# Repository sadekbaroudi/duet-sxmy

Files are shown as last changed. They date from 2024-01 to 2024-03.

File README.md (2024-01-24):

# duet

## CAUTION

This is based on the work of zzeneg. The intent of this fork is to convert the duet into a standard x / min y spacing verison, to be used with [CMY keycaps](https://github.com/sadekbaroudi/fingerpunch/tree/master/keycaps/CMY)  

In addition to this, I have added strong pinky stagger.  

Please reach out in the [fingerpunch discord server](https://fingerpunch.xyz/discord) if you are interested in building this.  

Everything below is the original readme, and has not been updated to reflect the changes in this repository.

--------------------------------------------------------------------------------------------

Wireless unibody/unsplit portable keyboard.

(https://www.youtube.com/watch?v=R7SToNp1SO8)

## Features

- wireless (nice!nano MCU)
- unibody that can be disassembled into two parts for traveling
- 40 Choc V1 switches
- 1 rotary encoder and 1 five-way switch
- reversible PCB
- 3D printed case
- nice!view support

## Photos

https://github.com/zzeneg/duet/assets/910255/740595a8-76a9-42da-903d-3cff3896a925





[...more](./images)

## Firmware

[zmk-config](https://github.com/zzeneg/zmk-config/tree/duet) - my custom keymap, use it for testing only. Fork and create your own keymap instead.

## Instructions

[Build guide](./guide/readme.md)

All files are available in repo or [GitHub release](https://github.com/zzeneg/duet/releases/latest).

## Support

If you like my work and want to support my future designs, please consider [sponsorship](https://github.com/sponsors/zzeneg).

#### Sponsors



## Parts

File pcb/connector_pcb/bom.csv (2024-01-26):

Designator | Footprint | Quantity | Value | LCSC Part #
H1, H2 | Hole_M2-TH | 2 | MountingHole
VIK_K1 | Connector_VIK-magnetic-keyboard | 1 | Connector_VIK-keyboard
VIK_K2, VIK_K4 | Connector_FFC-12pin-1mm-vertical | 2 | Connector_VIK-keyboard

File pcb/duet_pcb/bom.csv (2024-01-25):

Designator | Footprint | Quantity | Value | LCSC Part #
D1, D10, D11, D12, D13, D14, D15, D16, D17, D18, D19, D2, D20, D3, D4, D5, D6, D7, D8, D9 | Diode_1N4148-SOD123-reversible-flip3d | 20 | D
H1, H2, H3, H4, H5, H6, H7, H8 | Hole_M2-TH | 8 | MountingHole
J1 | MCU_nice-nano | 1 | N!N
J2 | Connector_JST-1x02-2.00mm | 1 | Conn_01x02_Socket
J4 | Display_nice-view | 1 | Display_nice-view
J8, J9 | Connector_FFC-12pin-1mm-horizontal | 2 | Conn_01x12_Socket
S1 | Button_5way-SKRHABE010 | 1 | Button_5way-SKRHABE010
SW1, SW10, SW11, SW12, SW13, SW14, SW15, SW16, SW17, SW18, SW19, SW2, SW20, SW3, SW4, SW5, SW6, SW7, SW8, SW9 | Switch_ChocV1-hotswap-minY-reversible | 20 | Switch
SW21 | Button_SW_SPST_SKQG_WithoutStem | 1 | SW_Push
SW22 | Switch_SPDT-PCM12 | 1 | SW_SPDT
SW23 | RotaryEncoder_EC11 | 1 | RotaryEncoder_Switch

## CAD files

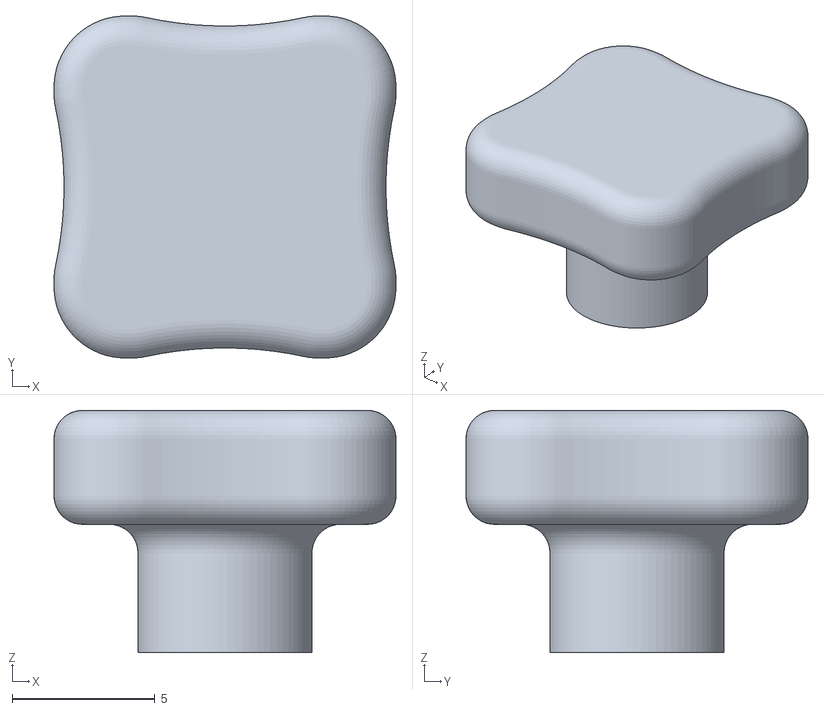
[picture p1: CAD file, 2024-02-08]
case/knob-5way-ergo-2.2.stl
12.0 x 12.0 x 8.50

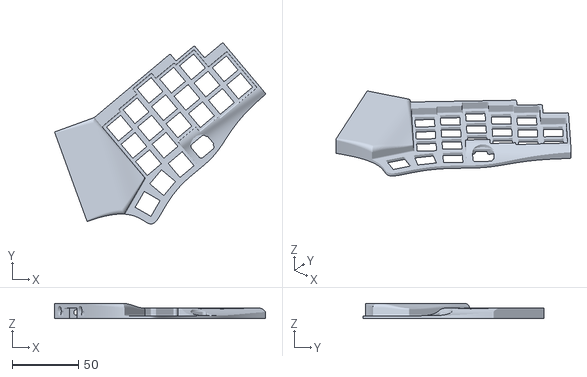
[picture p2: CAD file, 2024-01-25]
case/original/case_duet v39_top-right.stl
159.4 x 136.7 x 11.7

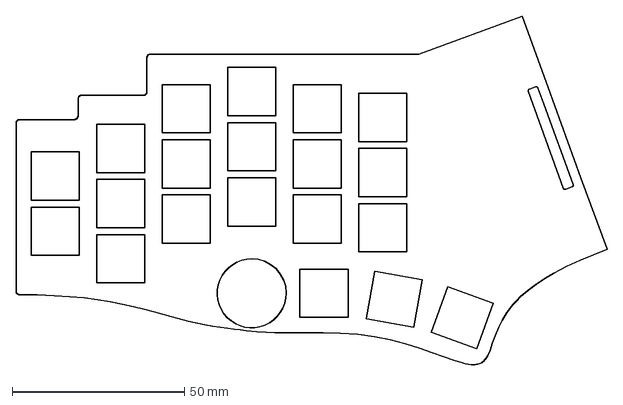
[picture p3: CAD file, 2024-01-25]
pcb/pcb-brd.dxf
171.5 x 101.1 mm

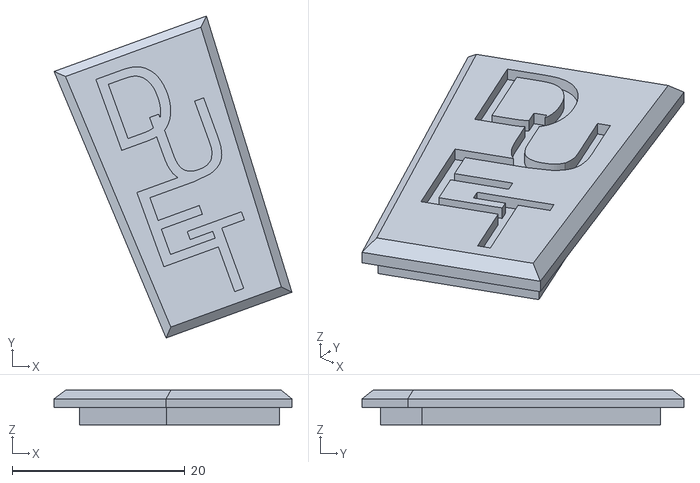
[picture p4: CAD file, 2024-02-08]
case/case_duet-emblem.stl
27.6 x 37.3 x 4.00

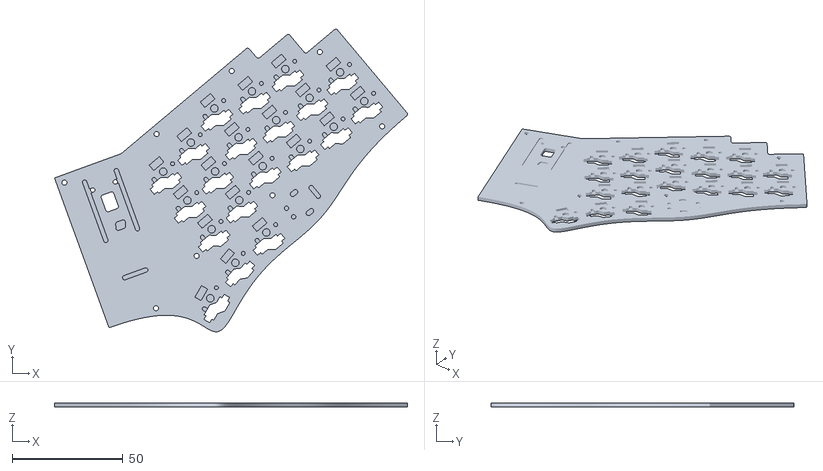
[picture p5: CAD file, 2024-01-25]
case/original/case_duet v39_bottom-right.stl
159.4 x 136.7 x 2.00

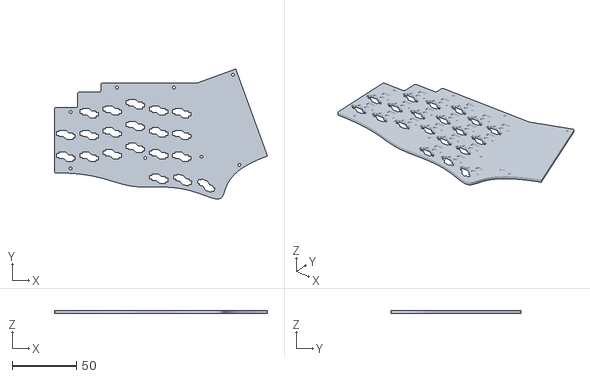
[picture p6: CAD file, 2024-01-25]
case/original/case_duet v39_bottom-left.stl
165.5 x 101.1 x 2.00

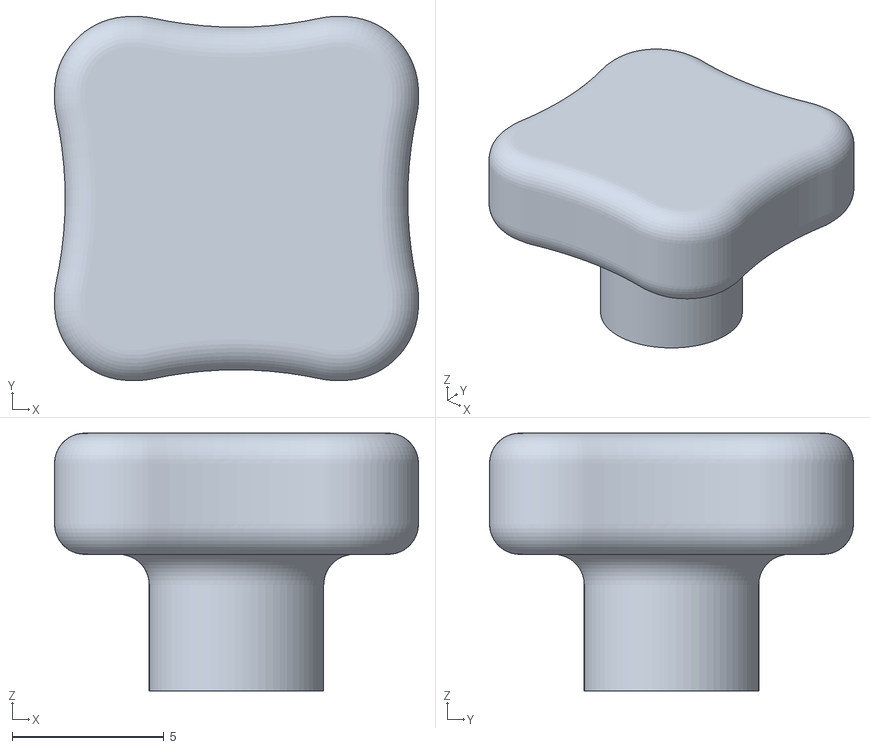
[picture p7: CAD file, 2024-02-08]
case/knob-5way-ergo-1.95.stl
12.0 x 12.0 x 8.50

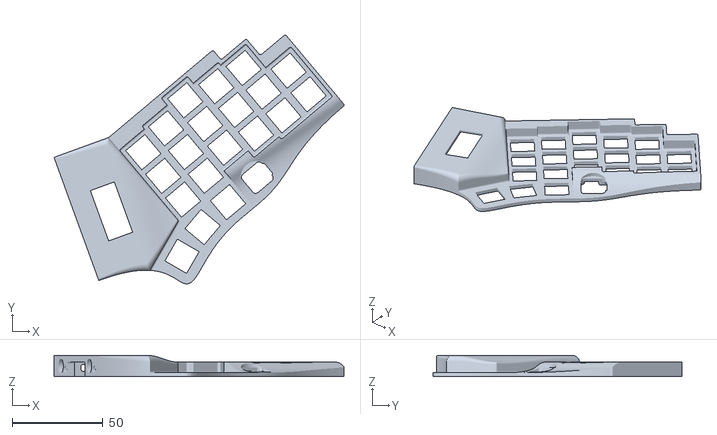
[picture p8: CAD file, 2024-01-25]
case/original/case_duet v39_top-right-display.stl
159.4 x 136.7 x 11.7

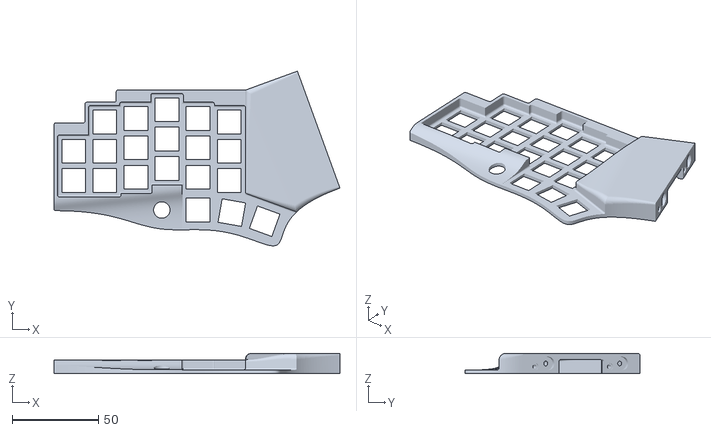
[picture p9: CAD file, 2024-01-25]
case/original/case_duet v39_top-left-cover.stl
165.5 x 101.1 x 11.7

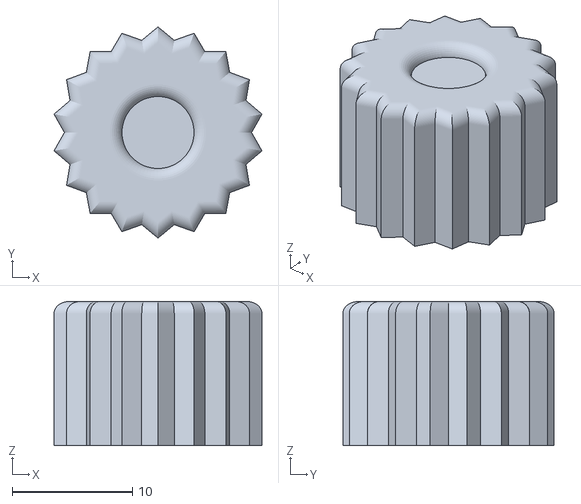
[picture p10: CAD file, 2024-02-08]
case/knob-ec12-12mm.stl
17.3 x 17.6 x 12.0

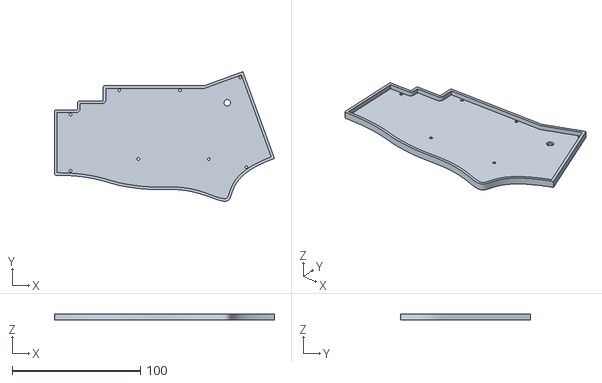
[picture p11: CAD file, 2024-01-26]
case/case_duet_sxmy_bottom-left.stl
171.5 x 101.1 x 4.72

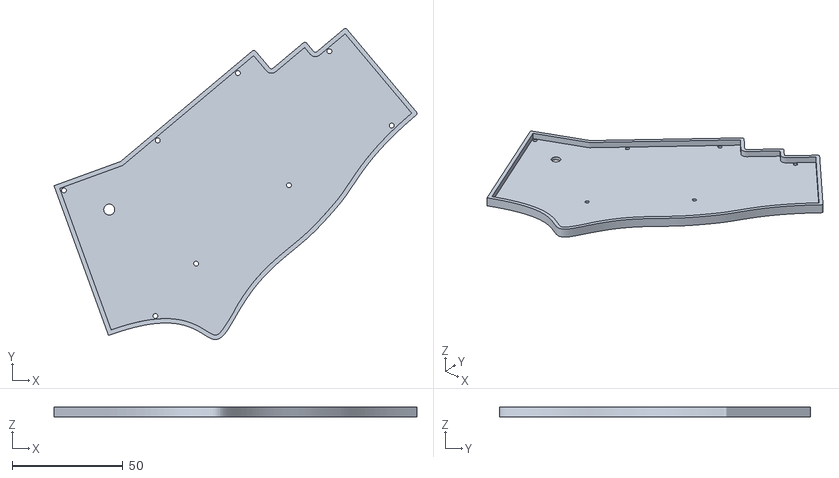
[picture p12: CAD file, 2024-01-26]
case/case_duet_sxmy_bottom-right.stl
164.0 x 140.5 x 4.72

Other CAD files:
case/knob-5way-ergo-2.1-fdm.stl
case/knob-5way-ergo-1.9.stl
case/knob-5way-ergo-2.0.stl
case/case_duet_sxmy_top-left-cover.stl
case/case_duet_sxmy_top-right.stl
case/case_duet_sxmy_top-right-display.stl

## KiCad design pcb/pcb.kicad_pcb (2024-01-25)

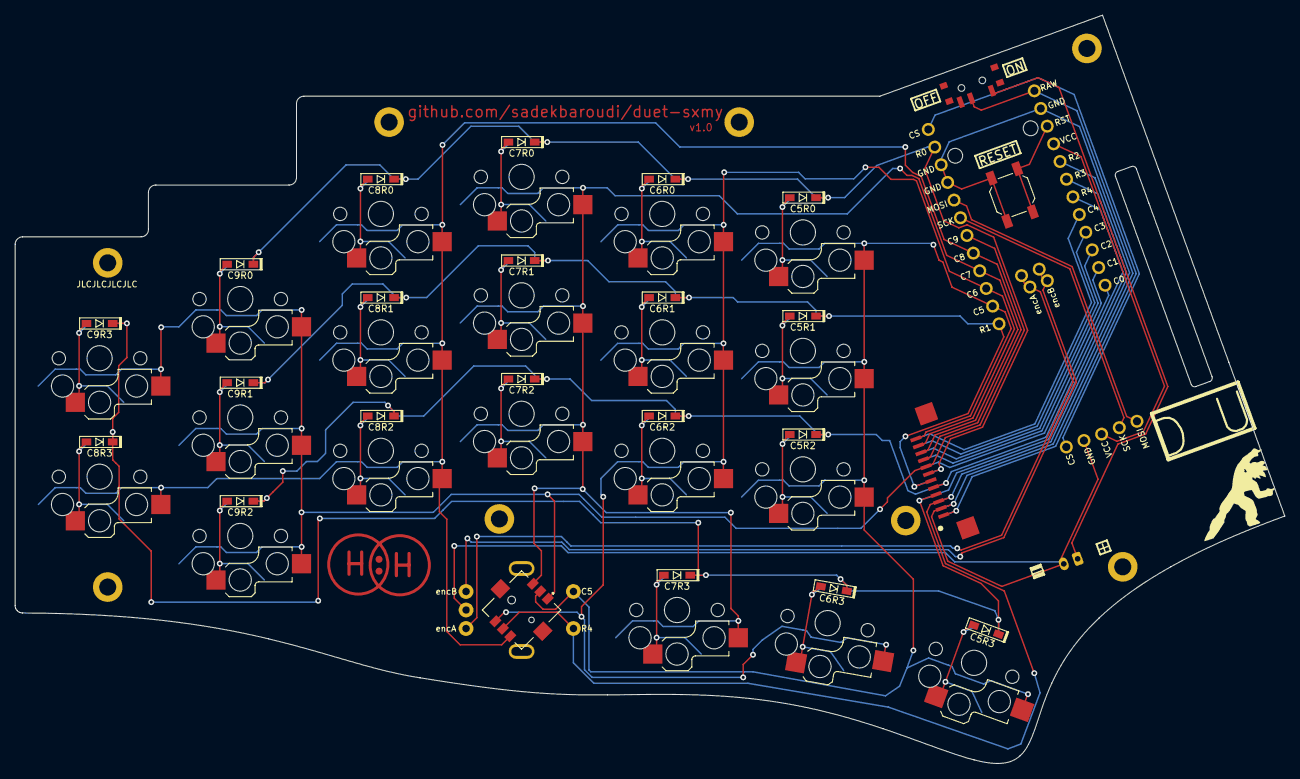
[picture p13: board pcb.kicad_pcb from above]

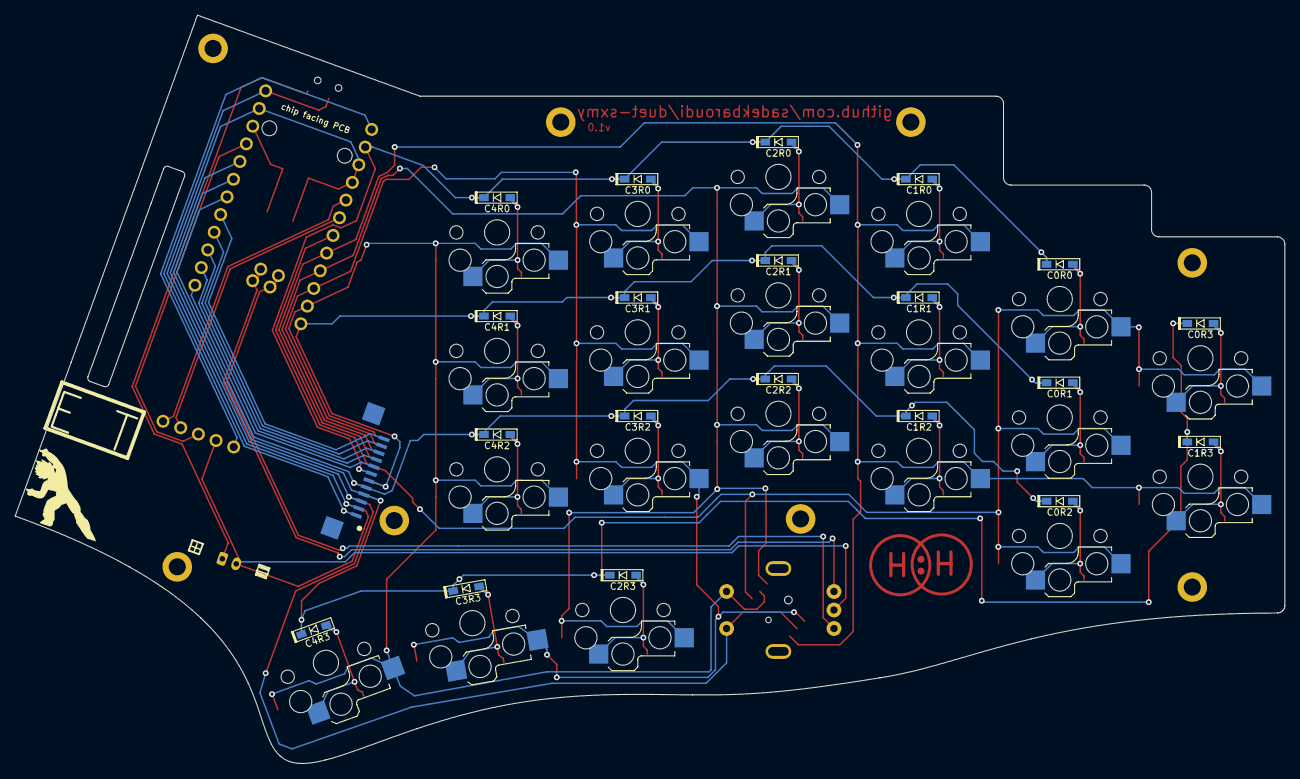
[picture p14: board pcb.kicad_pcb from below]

Board: 2 copper layers, 171.5 x 101.1 mm, 57 parts (23 on the bottom side), 45 nets.

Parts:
D1, D2, D3, D4, D5, D6, D7, D8, D9, D10, D11, D12, D13, D14, D15, D16, D17, D18, D19, D20: D; Diode_1N4148-SOD123-reversible-flip3d
H1, H2, H3, H4, H5, H6, H7, H8: MountingHole; Hole_M2-TH
J1: N!N; MCU_nice-nano
J2: Conn_01x02_Socket; Connector_JST-1x02-2.00mm
J4: Display_nice-view
J8, J9: Conn_01x12_Socket; Connector_FFC-12pin-1mm-horizontal
S1: Button_5way-SKRHABE010
SW1, SW2, SW3, SW4, SW5, SW6, SW7, SW8, SW9, SW10, SW11, SW12, SW13, SW14, SW15, SW16, SW17, SW18, SW19, SW20: Switch; Switch_ChocV1-hotswap-minY-reversible
SW21: SW_Push; Button_SW_SPST_SKQG_WithoutStem
SW22: SW_SPDT; Switch_SPDT-PCM12
SW23: RotaryEncoder_Switch; RotaryEncoder_EC11

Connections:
+3.3V: J1.21 (3V3), J4.3 (VCC)
BAT: J1.24 (BAT), J8.1, J9.12, SW22.2 (B)
BATIN: J2.1, SW22.1 (A)
CS: J1.1 (006), J4.5 (CS)
GND: J1.3 (GND), J1.4 (GND), J1.23 (GND), J2.2, J4.4 (GND), J8.2, J9.11, SW21.2, SW23.C
MOSI: J1.5 (017), J4.1 (MOSI)
unnamed: D1.2 (A), SW1.1
unnamed: D2.2 (A), SW2.1
unnamed: D3.2 (A), SW3.1
unnamed: D4.2 (A), SW4.1
unnamed: D5.2 (A), SW5.1
unnamed: D6.2 (A), SW6.1
unnamed: D7.2 (A), SW7.1
unnamed: D8.2 (A), SW8.1
unnamed: D9.2 (A), SW9.1
unnamed: D10.2 (A), SW10.1
unnamed: D11.2 (A), SW11.1
unnamed: D12.2 (A), SW12.1
unnamed: D13.2 (A), SW13.1
unnamed: D14.2 (A), SW14.1
unnamed: D15.2 (A), SW15.1
unnamed: D16.2 (A), SW16.1
unnamed: D17.2 (A), SW17.1
unnamed: D18.2 (A), SW18.1
unnamed: D19.2 (A), SW19.1
unnamed: D20.2 (A), SW20.1
RST: J1.22 (RST), SW21.1
SCK: J1.6 (020), J4.2 (SCK)
col0: J1.13 (009), J9.5
col1: J1.14 (010), J9.4
col2: J1.15 (111), J9.3
col3: J1.16 (113), J9.2
col4: J1.17 (115), J9.1
col5: J1.11 (104), J8.12, S1.2 (CENTER), SW5.2, SW10.2, SW15.2, SW20.2, SW23.S1
col6: J1.10 (011), J8.11, S1.6 (D), SW4.2, SW9.2, SW14.2, SW19.2
col7: J1.9 (100), J8.10, S1.3 (C), SW3.2, SW8.2, SW13.2, SW18.2
col8: J1.8 (024), J8.9, S1.4 (B), SW2.2, SW7.2, SW12.2, SW17.2
col9: J1.7 (022), J8.8, S1.1 (A), SW1.2, SW6.2, SW11.2, SW16.2
encA: J1.32 (102), SW23.A
encB: J1.33 (107), SW23.B
row0: D1.1 (K), D2.1 (K), D3.1 (K), D4.1 (K), D5.1 (K), J1.2 (008), J8.7, J9.6
row1: D6.1 (K), D7.1 (K), D8.1 (K), D9.1 (K), D10.1 (K), J1.12 (106), J8.6, J9.7
row2: D11.1 (K), D12.1 (K), D13.1 (K), D14.1 (K), D15.1 (K), J1.18 (002), J8.5, J9.8
row3: D16.1 (K), D17.1 (K), D18.1 (K), D19.1 (K), D20.1 (K), J1.19 (029), J8.4, J9.9
row4: J1.20 (031), J8.3, J9.10, S1.5 (COMMON), SW23.S2

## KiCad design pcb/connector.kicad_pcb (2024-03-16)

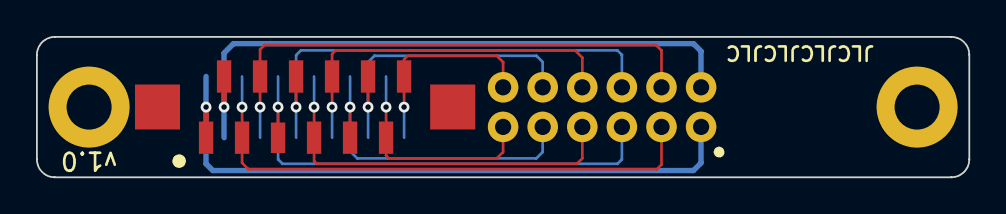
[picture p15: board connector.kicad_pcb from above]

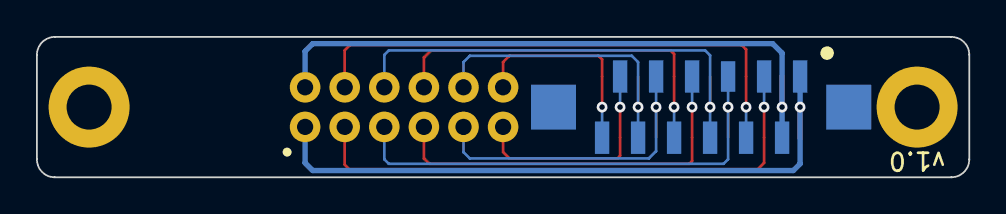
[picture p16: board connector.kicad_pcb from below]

Board: 2 copper layers, 51.8 x 7.8 mm, 5 parts (2 on the bottom side), 12 nets.

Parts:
H1, H2: MountingHole; Hole_M2-TH
VIK_K1: Connector_VIK-keyboard; Connector_VIK-magnetic-keyboard
VIK_K2, VIK_K4: Connector_VIK-keyboard; Connector_FFC-12pin-1mm-vertical

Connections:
unnamed: VIK_K1.1 (3V3), VIK_K2.1 (3V3), VIK_K4.1 (3V3)
unnamed: VIK_K1.6 (5V), VIK_K2.6 (5V), VIK_K4.6 (5V)
unnamed: VIK_K1.10 (CS), VIK_K2.10 (CS), VIK_K4.10 (CS)
unnamed: VIK_K1.2 (GND), VIK_K2.2 (GND), VIK_K4.2 (GND)
unnamed: VIK_K1.7 (GND), VIK_K2.7 (GND), VIK_K4.7 (GND)
unnamed: VIK_K1.9 (GPIO), VIK_K2.9 (GPIO), VIK_K4.9 (GPIO)
unnamed: VIK_K1.11 (MISO), VIK_K2.11 (MISO), VIK_K4.11 (MISO)
unnamed: VIK_K1.8 (MOSI), VIK_K2.8 (MOSI), VIK_K4.8 (MOSI)
unnamed: VIK_K1.5 (RGB_IN), VIK_K2.5 (RGB_IN), VIK_K4.5 (RGB_IN)
unnamed: VIK_K1.4 (SCL), VIK_K2.4 (SCL), VIK_K4.4 (SCL)
unnamed: VIK_K1.12 (SCLK), VIK_K2.12 (SCLK), VIK_K4.12 (SCLK)
unnamed: VIK_K1.3 (SDA), VIK_K2.3 (SDA), VIK_K4.3 (SDA)

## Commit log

2024-01-24 converting duet to standard x and min y spacing, along with strong pinky stagger, WIP
    [pcb.kicad_pcb, pcb.kicad_sch]
2024-01-25 rerouted with the new layout, ready for production test
    [bom.csv, designators.csv, pcb.kicad_pcb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]
2024-01-25 moved mounting hole, added updated dxfs, added sxmy cases, still need to do bottom plates
    [case_duet v39_bottom-left.stl, case_duet v39_bottom-right.stl, case_duet v39_top-left-cover.stl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]
2024-01-26 moved gerbers into their own folders
    [bom.csv, designators.csv, positions.csv]
2024-01-26 added bottom plates for sxmy
    [case_duet_sxmy_bottom-left.stl, case_duet_sxmy_bottom-right.stl]
2024-02-08 added emblem to snap into display hole, and variations on the original knobs
    [case_duet-emblem.stl, knob-5way-ergo-1.9.stl, knob-5way-ergo-1.95.stl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]
2024-03-16 removed original duet pcb gerbers to avoid confusion
    [bom.csv, connector.kicad_pcb, designators.csv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]
